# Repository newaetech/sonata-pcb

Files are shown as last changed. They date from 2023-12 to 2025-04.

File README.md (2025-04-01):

# Sonata PCB Sources for Development Board

Sonata is a system for evaluating the usage of [CHERIoT Ibex core](https://github.com/microsoft/cheriot-ibex) as a microcontroller for embedded, IoT and Operational Technology applications.
See the main [Sonata System](https://github.com/lowRISC/sonata-system) repository for more information.

This repository contains the source files for the PCB and related information about the development board.

Sonata is part of the [Sunburst Project](https://www.sunburst-project.org) funded by [UKRI](https://www.ukri.org/) / [DSbD](https://www.dsbd.tech/).

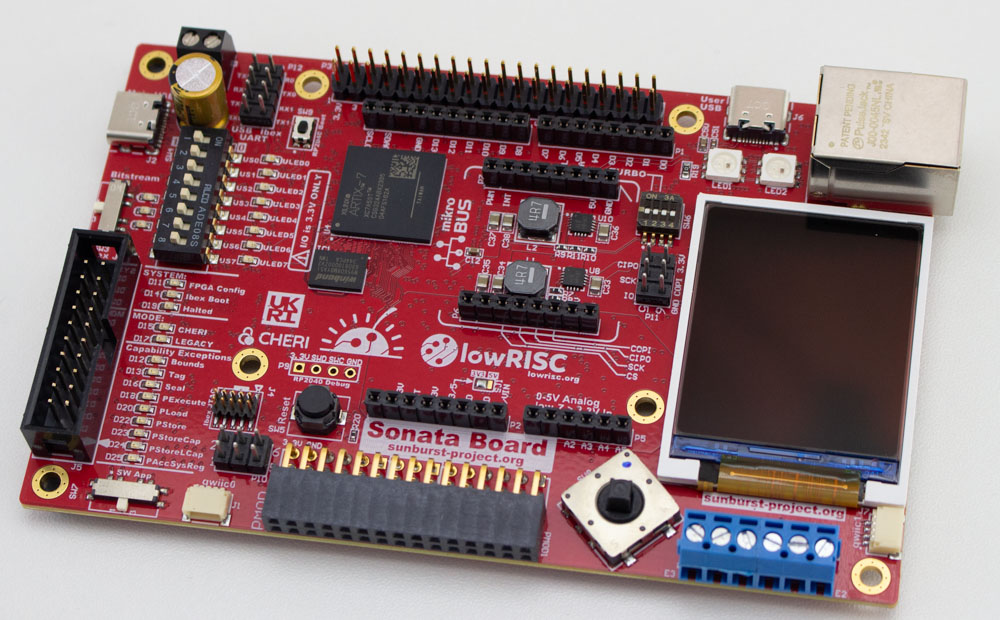
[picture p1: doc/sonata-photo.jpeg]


## Associated Repos for Testing

See the [https://github.com/newaetech/sonata-rp2040](https://github.com/newaetech/sonata-rp2040) repo for the RP2040 firmware.

See the [https://github.com/newaetech/sonata-fpga-test](https://github.com/newaetech/sonata-fpga-test) repo for the FPGA test bitstream project, which is used only for testing certain features, or can be used as the base for your own FPGA project. Most users should see the [Sonata System](https://github.com/lowRISC/sonata-system) repository instead to build the reference Sonata FPGA.

## License

Unless otherwise noted, everything in the repository is covered by the [Apache License](https://www.apache.org/licenses/LICENSE-2.0.html), Version 2.0. Where reference is made to the CC-SA license (particular for the PCB files), the license is the [Creative Commons Share Alike 4.0 License](https://creativecommons.org/licenses/by-sa/4.0/).

## PCB Status

### Sonata-One

Rev0.9 Gerbers are the production version. Prior gerbers are currently kept but will be removed (still available in the GIT history).

The original PCB was designed in Altium, and the design then ported to KiCAD. The production gerbers are generated from the Altium PCB.

### Sonata-XL (Sonata-A200)

A modified version of Sonata with a larger (Artix A200) FPGA is also available. This version was designed for various test environments.
It may be available in future versions.

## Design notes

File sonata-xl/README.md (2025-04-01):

# SonataXL

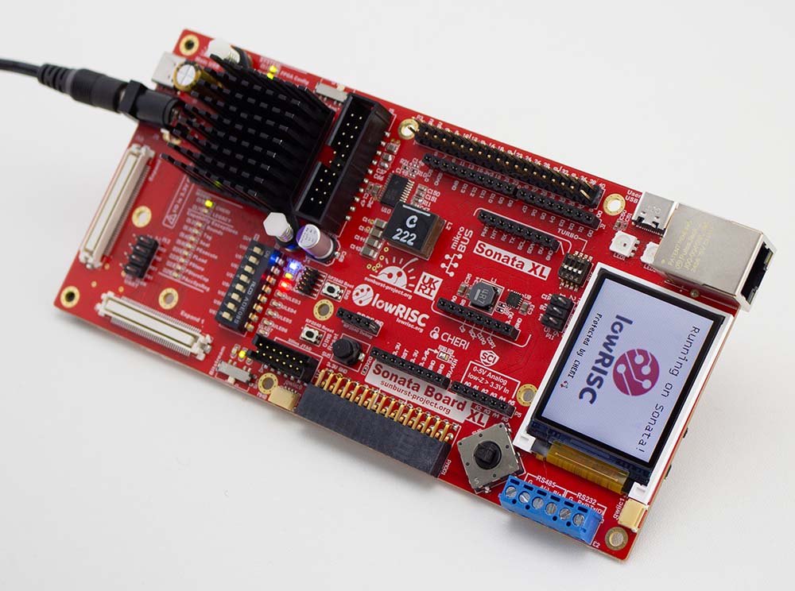
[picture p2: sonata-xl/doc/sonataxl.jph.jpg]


SonataXL has a larger A200 FPGA, as well as 2x high density pin headers for various expansion boards.

It uses the same drag & drop RP2040 firmware as the Sonata board. The only difference in peripherals is there
is no HyperRAM on this board.

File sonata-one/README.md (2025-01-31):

# Sonata-One PCB

This folder contains the Sonata-One PCB.

The original design was developed in Altium, which was then ported to KiCAD for better accessability.

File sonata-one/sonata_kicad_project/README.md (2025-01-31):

# SONATA-ONE-KICAD
 KiCAD Design files for Sonata PCB, part of the Sunburst Project
 
 Please sumit an issue if you discover problems with this repo. Design converted and refactored from the original altium files.

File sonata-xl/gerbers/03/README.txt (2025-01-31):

GENERAL
----------
Finish: ENIG
Soldermask: Red
Silkscreen: White
Board Thickness: 1.6mm

168 mm * 80 mm

Min drill = 0.2mm
Space/Trace = 5mil

PCB STACKUP:
--------------------------------
 .GTO Top Silkcreen
 .GTS Top Soldermask
 .GTL TOP COPPER       (LAYER 1)
 .G1  INNER 1          (LAYER 2)
 .G2  INNER 2          (LAYER 3)
 .G3  INNER 3          (LAYER 4)
 .G4  INNER 4          (LAYER 5)
 .G5  INNER 5          (LAYER 6)
 .G6  INNER 6          (LAYER 7)
 .GBL BOTTOM COPPER    (LAYER 8)
 .GTS Bottom Soldermask
 .GBO Bottom Silkscreen

ADDITIONAL FILES:
--------------------------------
 .NCDRILL - NC Drill
 .GTP Top Stencil
 .GBP Bottom Stencil
 .GM1 board routing/outline

BOARD CONSTRUCTION
--------------------------------
Standard board stackup spacing for 8-layer 0.062" PCB ok

E-TEST
------

PCBs must be 100% electrically tested. Can provide netlist in preferred format on request.

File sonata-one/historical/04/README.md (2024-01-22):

These gerbers had critical errors and have been removed to avoid accidents.

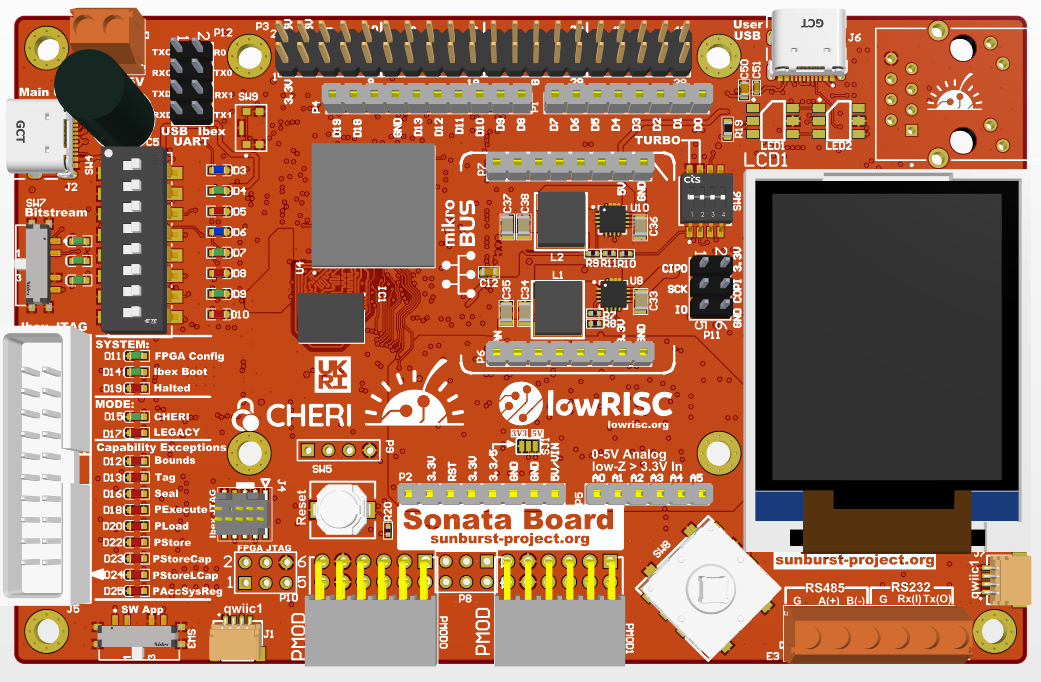
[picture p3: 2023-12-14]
doc/sonata-render.png

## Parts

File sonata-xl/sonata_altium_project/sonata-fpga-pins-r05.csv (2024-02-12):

# Altium Pin Report File
Pin Designator | Net Name | Display Name | IO Bank | IO Standard | Slew Rate | Drive Strength | IO Pin | Vref Pin | CLK Pin | Config Pin | Special Pin | Group | Differential Pair
A1 | HYPERRAM_DQ3 | IO_L9N_T1_DQS_AD7N_35
A2 | GND | GND
A3 | ANALOG5_N | IO_L8N_T1_AD14N_35
A4 | ANALOG5_P | IO_L8P_T1_AD14P_35
A5 | ANALOG2_N | IO_L3N_T0_DQS_AD5N_35
A6 | ANALOG2_P | IO_L3P_T0_DQS_AD5P_35
A7 | VCC1V8 | VCCO_35
A8 | APPSPI_CLK | IO_L12N_T1_MRCC_16
A9 | APPSPI_D3 | IO_L14N_T2_SRCC_16
A10 | APPSPI_D2 | IO_L14P_T2_SRCC_16
A11 | USRLED5 | IO_L4N_T0_15
A12 | GND | GND
A13 | USRSW6 | IO_L9P_T1_DQS_AD3P_15
A14 | USRSW7 | IO_L9N_T1_DQS_AD3N_15
A15 | USRSW4 | IO_L8P_T1_AD10P_15
A16 | USRSW5 | IO_L8N_T1_AD10N_15
A17 | VCCIO | VCCO_15
A18 | NetR172_3A | IO_L10N_T1_AD11N_15
B1 | HYPERRAM_DQ0 | IO_L9P_T1_DQS_AD7P_35
B2 | HYPERRAM_DQ5 | IO_L10N_T1_AD15N_35
B3 | MICROSD_DET | IO_L10P_T1_AD15P_35
B4 | ANALOG4_N | IO_L7N_T1_AD6N_35
B5 | GND | GND
B6 | ANALOG1_N | IO_L2N_T0_AD12N_35
B7 | ANALOG1_P | IO_L2P_T0_AD12P_35
B8 | ANALOG5_DIGITAL | IO_L12P_T1_MRCC_16
B9 | ANALOG4_DIGITAL | IO_L11N_T1_SRCC_16
B10 | VCCIO | VCCO_16
B11 | USRLED4 | IO_L4P_T0_15
B12 | USRLED3 | IO_L3N_T0_DQS_AD1N_15
B13 | USRLED0 | IO_L2P_T0_AD8P_15
B14 | USRLED1 | IO_L2N_T0_AD8N_15
B15 | GND | GND
B16 | USRSW2 | IO_L7P_T1_AD2P_15
B17 | USRSW3 | IO_L7N_T1_AD2N_15
B18 | NetR172_1A | IO_L10P_T1_AD11P_15
C1 | HYPERRAM_DQ6 | IO_L16N_T2_35
C2 | HYPERRAM_nRST | IO_L16P_T2_35
C3 | VCC1V8 | VCCO_35
C4 | ANALOG4_P | IO_L7P_T1_AD6P_35
C5 | ANALOG0_N | IO_L1N_T0_AD4N_35
C6 | ANALOG0_P | IO_L1P_T0_AD4P_35
C7 | NAVSW_2 | IO_L4N_T0_35
C8 | GND | GND
C9 | ANALOG3_DIGITAL | IO_L11P_T1_SRCC_16
C10 | APPSPI_D1 | IO_L13N_T2_MRCC_16
C11 | APPSPI_D0 | IO_L13P_T2_MRCC_16
C12 | USRLED2 | IO_L3P_T0_DQS_AD1P_15
C13 | VCCIO | VCCO_15
C14 | ANALOG2_DIGITAL | IO_L1N_T0_AD0N_15
C15 | NetR173_2A | IO_L12N_T1_MRCC_15
C16 | USR_JTAG_TRST | IO_L20P_T3_A20_15
C17 | SER0_TX | IO_L20N_T3_A19_15
C18 | GND | GND
D1 | GND | GND
D2 | HYPERRAM_DQ7 | IO_L14N_T2_SRCC_35
D3 | SELSW0 | IO_L12N_T1_MRCC_35
D4 | ETHMAC_CIPO | IO_L11N_T1_SRCC_35
D5 | ETHMAC_COPI | IO_L11P_T1_SRCC_35
D6 | VCC1V8 | VCCO_35
D7 | NAVSW_4 | IO_L6N_T0_VREF_35
D8 | NAVSW_1 | IO_L4P_T0_35
D9 | RGBLED0 | IO_L6N_T0_VREF_16
D10 | APPSPI_CS | IO_L19N_T3_VREF_16
D11 | GND | GND
D12 | USRSW0 | IO_L6P_T0_15
D13 | USRSW1 | IO_L6N_T0_VREF_15
D14 | ANALOG1_DIGITAL | IO_L1P_T0_AD0P_15
D15 | NetR173_1A | IO_L12P_T1_MRCC_15
D16 | VCCIO | VCCO_15
D17 | NetR176_3A | IO_L16N_T2_A27_15
D18 | SER0_RX | IO_L21N_T3_DQS_A18_15
E1 | HYPERRAM_DQ4 | IO_L18N_T2_35
E2 | HYPERRAM_DQ1 | IO_L14P_T2_SRCC_35
E3 | ETHMAC_SCLK | IO_L12P_T1_MRCC_35
E4 | GND | GND
E5 | ANALOG3_N | IO_L5N_T0_AD13N_35
E6 | ANALOG3_P | IO_L5P_T0_AD13P_35
E7 | NAVSW_3 | IO_L6P_T0_35
E8 | VCC1V8 | VCCBATT_0
E9 | FPGA_CCLK | CCLK_0
E10 | FPGA_TCK | TCK_0
E11 | FPGA_TDI | TDI_0
E12 | FPGA_TMS | TMS_0
E13 | FPGA_TDO | TDO_0
E14 | GND | GND
E15 | USR_JTAG_TCK | IO_L11P_T1_SRCC_15
E16 | NetR172_2A | IO_L11N_T1_SRCC_15
E17 | NetR176_2A | IO_L16P_T2_A28_15
E18 | SER1_TX | IO_L21P_T3_DQS_15
F1 | HYPERRAM_RWDS | IO_L18P_T2_35
F2 | VCC1V8 | VCCO_35
F3 | SELSW2 | IO_L13N_T2_MRCC_35
F4 | SELSW1 | IO_L13P_T2_MRCC_35
F5 | NAVSW_0 | IO_0_35
F6 | USRUSB_V_N | IO_L19N_T3_VREF_35
F7 | GND | GND
F8 | VCCINT | VCCINT
F9 | GND | GND
F10 | VCCINT | VCCBRAM
F11 | GND | GND
F12 | VCC1V8 | VCCAUX
F13 | USRLED6 | IO_L5P_T0_AD9P_15
F14 | USRLED7 | IO_L5N_T0_AD9N_15
F15 | NetR174_3A | IO_L14P_T2_SRCC_15
F16 | NetR174_2A | IO_L14N_T2_SRCC_15
F17 | GND | GND
F18 | NetR194_2A | IO_L22N_T3_A16_15
G1 | USRUSB_SPD | IO_L17N_T2_35
G2 | HYPERRAM_CK_N | IO_L15N_T2_DQS_35
G3 | USRUSB_VMO | IO_L20N_T3_35
G4 | USRUSB_VPO | IO_L20P_T3_35
G5 | VCC1V8 | VCCO_35
G6 | USRUSB_V_P | IO_L19P_T3_35
G7 | VCCINT | VCCINT
G8 | GND | GND
G9 | VCCINT | VCCINT
G10 | GND | GND
G11 | VCCINT | VCCBRAM
G12 | GND | GND
G13 | ANALOG0_DIGITAL | IO_0_15
G14 | NetR174_4A | IO_L15N_T2_DQS_ADV_B_15
G15 | VCCIO | VCCO_15
G16 | NetR173_4A | IO_L13N_T2_MRCC_15
G17 | USR_JTAG_TDI | IO_L18N_T2_A23_15
G18 | SER1_RX | IO_L22P_T3_A17_15
H1 | HYPERRAM_DQ2 | IO_L17P_T2_35
H2 | HYPERRAM_CK_P | IO_L15P_T2_DQS_35
H3 | GND | GND
H4 | USRUSB_SOFTCN | IO_L21N_T3_DQS_35
H5 | ETHMAC_CS | IO_L24N_T3_35
H6 | ETHMAC_INTR | IO_L24P_T3_35
H7 | GND | GND
H8 | VCCINT | VCCINT
H9 | XADC_AGND | GNDADC_0
H10 | +1V85_XADC_VCC | VCCADC_0
H11 | GND | GND
H12 | VCC1V8 | VCCAUX
H13 | GND | GND
H14 | NetR174_1A | IO_L15P_T2_DQS_15
H15 | USR_JTAG_TMS | IO_L19N_T3_A21_VREF_15
H16 | NetR173_3A | IO_L13P_T2_MRCC_15
H17 | NetR172_4A | IO_L18P_T2_A24_15
H18 | VCCIO | VCCO_15
J1 | VCC1V8 | VCCO_35
J2 | HYPERRAM_CS | IO_L22N_T3_35
J3 | USRUSB_OE | IO_L22P_T3_35
J4 | USRUSB_RCV | IO_L21P_T3_DQS_35
J5 | ETHMAC_RST | IO_25_35
J6 | GND | GND
J7 | VCCINT | VCCINT
J8 | GND | GND
J9 | XADC_VREF_N | VREFN_0
J10 |  | VP_0
J11 | VCCINT | VCCINT
J12 | GND | GND
J13 | NetR176_1A | IO_L17N_T2_A25_15
J14 | USR_JTAG_TDO | IO_L19P_T3_A22_15
J15 | NetR186_1 | IO_L24N_T3_RS0_15
J16 | GND | GND
J17 | NetR194_3A | IO_L23P_T3_FOE_B_15
J18 | NetR194_1A | IO_L23N_T3_FWE_B_15
K1 | USRUSB_VBUSDETECT | IO_L23N_T3_35
K2 | USRUSB_SUS | IO_L23P_T3_35
K3 | CHERIERR3 | IO_L2P_T0_34
K4 | VCCIO | VCCO_34
K5 | LED_LEGACY | IO_L5P_T0_34
K6 | CHERIERR0 | IO_0_34
K7 | GND | GND
K8 | VCCINT | VCCINT
K9 |  | VN_0
K10 | XADC_VREF_P | VREFP_0
K11 | GND | GND
K12 | VCC1V8 | VCCAUX
K13 | NetR176_4A | IO_L17P_T2_A26_15
K14 | VCCIO | VCCO_15
K15 | NetR194_4A | IO_L24P_T3_RS1_15
K16 | NetR187_1 | IO_25_15
K17 | NetR175_2A | IO_L1P_T0_D00_MOSI_14
K18 | RP2040_TX | IO_L1N_T0_D01_DIN_14
L1 | CHERIERR1 | IO_L1P_T0_34
L2 | GND | GND
L3 | CHERIERR4 | IO_L2N_T0_34
L4 | LED_CHERI | IO_L5N_T0_34
L5 | LED_BOOTOK | IO_L6N_T0_VREF_34
L6 | LED_HALTED | IO_L6P_T0_34
L7 | VCCINT | VCCINT
L8 | GND | GND
L9 |  | DXN_0
L10 |  | DXP_0
L11 | VCCINT | VCCINT
L12 | GND | GND
L13 | NetR175_3A | IO_L6P_T0_FCS_B_14
L14 | NetR177_3A | IO_L2P_T0_D02_14
L15 | NetR183_1A | IO_L3P_T0_DQS_PUDC_B_14
L16 | NetR177_4A | IO_L3N_T0_DQS_EMCCLK_14
L17 | VCCIO | VCCO_14
L18 | NetR175_1A | IO_L4P_T0_D04_14
M1 | CHERIERR2 | IO_L1N_T0_34
M2 | CHERIERR8 | IO_L4N_T0_34
M3 | CHERIERR7 | IO_L4P_T0_34
M4 | 485_DE | IO_L16P_T2_34
M5 | GND | GND
M6 | 485_DI | IO_L18P_T2_34
M7 | GND | GND
M8 | VCCINT | VCCINT
M9 | GND | GND
M10 | VCCINT | VCCINT
M11 | GND | GND
M12 | VCC1V8 | VCCAUX
M13 | NetR169_1 | IO_L6N_T0_D08_VREF_14
M14 | NetR177_2A | IO_L2N_T0_D03_14
M15 | GND | GND
M16 | NetR175_4A | IO_L10P_T1_D14_14
M17 | RP2040_RX | IO_L10N_T1_D15_14
M18 | NetR189_4A | IO_L4N_T0_D05_14
N1 | CHERIERR6 | IO_L3N_T0_DQS_34
N2 | CHERIERR5 | IO_L3P_T0_DQS_34
N3 | VCCIO | VCCO_34
N4 | 485_REn | IO_L16N_T2_34
N5 | LCD_BACKLIGHT | IO_L13P_T2_MRCC_34
N6 | 232_RX | IO_L18N_T2_34
N7 | VCCINT | VCCINT
N8 | GND | GND
N9 | VCCINT | VCCINT
N10 | GND | GND
N11 | VCCINT | VCCINT
N12 | GND | GND
N13 | VCCIO | VCCO_14
N14 | NetR182_3A | IO_L8P_T1_D11_14
N15 | NetR177_1A | IO_L11P_T1_SRCC_14
N16 | NetR182_4A | IO_L11N_T1_SRCC_14
N17 | NetR168_1 | IO_L9P_T1_DQS_14
N18 | GND | GND
P1 | GND | GND
P2 | NetR178_1A | IO_L15P_T2_DQS_34
P3 | 232_TX | IO_L14N_T2_SRCC_34
P4 | RP2040_SPARE | IO_L14P_T2_SRCC_34
P5 | LCD_CS | IO_L13N_T2_MRCC_34
P6 | VCCIO | VCCO_34
P7 | FPGA_INITB | INIT_B_0
P8 | VCCIO | CFGBVS_0
P9 | FPGA_PGMB | PROGRAM_B_0
P10 | FPGA_DONE | DONE_0
P11 | VCCIO | M2_0
P12 | VCCIO | M0_0
P13 | VCCIO | M1_0
P14 | NetR191_4A | IO_L8N_T1_D12_14
P15 | MAINCLK | IO_L13P_T2_MRCC_14
P16 | VCCIO | VCCO_14
P17 | NetR179_3A | IO_L12P_T1_MRCC_14
P18 | NetR182_2A | IO_L9N_T1_DQS_D13_14
R1 | NetR178_2A | IO_L17P_T2_34
R2 | 485_RO | IO_L15N_T2_DQS_34
R3 | LCD_COPI | IO_L11P_T1_SRCC_34
R4 | GND | GND
R5 | LCD_CLK | IO_L19N_T3_VREF_34
R6 | LCD_RST | IO_L19P_T3_34
R7 | MICROSD_DAT1 | IO_L23P_T3_34
R8 | MICROSD_CMD | IO_L24P_T3_34
R9 | VCCIO | VCCO_0
R10 | NetR189_1A | IO_25_14
R11 | NetR183_3A | IO_0_14
R12 | NetR188_3A | IO_L5P_T0_D06_14
R13 | NetR181_3A | IO_L5N_T0_D07_14
R14 | GND | GND
R15 | NetR182_1A | IO_L13N_T2_MRCC_14
R16 | NetR191_1A | IO_L15P_T2_DQS_RDWR_B_14
R17 | NetR191_2A | IO_L12N_T1_MRCC_14
R18 | NetR191_3A | IO_L7P_T1_D09_14
T1 | NetR178_3A | IO_L17N_T2_34
T2 | VCCIO | VCCO_34
T3 | NetR180_1A | IO_L11N_T1_SRCC_34
T4 | FPGAIO_TURBO | IO_L12N_T1_MRCC_34
T5 | NRST | IO_L12P_T1_MRCC_34
T6 | NetR184_2A | IO_L23N_T3_34
T7 | GND | GND
T8 | MICROSD_DAT3 | IO_L24N_T3_34
T9 | NetR185_2A | IO_L24P_T3_A01_D17_14
T10 | NetR185_3A | IO_L24N_T3_A00_D16_14
T11 | NetR188_1A | IO_L19P_T3_A10_D26_14
T12 | VCCIO | VCCO_14
T13 | NetR181_1A | IO_L23P_T3_A03_D19_14
T14 | RP2040_CLK | IO_L14P_T2_SRCC_14
T15 | NetR183_4A | IO_L14N_T2_SRCC_14
T16 | NetR190_2A | IO_L15N_T2_DQS_DOUT_CSO_B_14
T17 | GND | GND
T18 | NetR190_4A | IO_L7N_T1_D10_14
U1 | NetR178_4A | IO_L7P_T1_34
U2 | NetR180_3A | IO_L9P_T1_DQS_34
U3 | NetR171_1 | IO_L8N_T1_34
U4 | LCD_DC | IO_L8P_T1_34
U5 | VCCIO | VCCO_34
U6 | MICROSD_CLK | IO_L22N_T3_34
U7 | NetR170_1A | IO_L22P_T3_34
U8 | NetR184_1A | IO_25_34
U9 | NetR170_4A | IO_L21P_T3_DQS_34
U10 | GND | GND
U11 | NetR189_3A | IO_L19N_T3_A09_D25_VREF_14
U12 | NetR188_2A | IO_L20P_T3_A08_D24_14
U13 | NetR188_4A | IO_L23N_T3_A02_D18_14
U14 | NetR181_2A | IO_L22P_T3_A05_D21_14
U15 | VCCIO | VCCO_14
U16 | NetR190_3A | IO_L18P_T2_A12_D28_14
U17 | NetR179_4A | IO_L17P_T2_A14_D30_14
U18 | NetR190_1A | IO_L17N_T2_A13_D29_14
V1 | NetR180_2A | IO_L7N_T1_34
V2 | NetR180_4A | IO_L9N_T1_DQS_34
V3 | GND | GND
V4 | MICROSD_DAT0 | IO_L10N_T1_34
V5 | MICROSD_DAT2 | IO_L10P_T1_34
V6 | NetR184_3A | IO_L20N_T3_34
V7 | NetR170_3A | IO_L20P_T3_34
V8 | VCCIO | VCCO_34
V9 | NetR170_2A | IO_L21N_T3_DQS_34
V10 | NetR185_1A | IO_L21P_T3_DQS_14
V11 | NetR185_4A | IO_L21N_T3_DQS_A06_D22_14
V12 | NetR189_2A | IO_L20N_T3_A07_D23_14
V13 | GND | GND
V14 | NetR181_4A | IO_L22N_T3_A04_D20_14
V15 | NetR183_2A | IO_L16P_T2_CSI_B_14
V16 | NetR179_1A | IO_L16N_T2_A15_D31_14
V17 | NetR179_2A | IO_L18N_T2_A11_D27_14
V18 | VCCIO | VCCO_14

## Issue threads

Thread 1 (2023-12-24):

0.2 pcb - FTDI chip has shorted EEPROM pins

colinoflynn, 2023-12-24:
At some point between initial design & PCB layout the FTDI EEPROM got dragged and Altium decided we should short those pins together. This wasn't caught & requires a PCB mod to fix. Otherwise the FTDI chip won't come online.

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

colinoflynn, 2024-01-12:
Issue is fixed on 0.3 PCB (now on order) & will be tested once board is built. Issue will be closed once fix is confirmed.

Closed 2024-02-25.

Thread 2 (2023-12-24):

0.2 pcb - activeBOM PN issue with AVCC regulator

colinoflynn, 2023-12-24:
P/N for AVCC regulator was wrong on initial DK order, need to check if that was an issue with ActiveBom & the manufacture solution. P/N in the schematic sheet is correct.

Closed 2024-02-25.

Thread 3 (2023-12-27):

0.2 pcb - LCD connector is mirrored

colinoflynn, 2023-12-27:
LCD connector is mirrored & requires flywires to mount LCD:

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

colinoflynn, 2024-01-12:
Issue is fixed on 0.3 PCB (now on order) & will be tested once board is built. Issue will be closed once fix is confirmed.

Closed 2024-02-25.

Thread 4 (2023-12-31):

0.2 pcb - DIN not routed to RP2040

colinoflynn, 2023-12-31:
Do to a pin swap marathon where the DIN wasn't locked, it no longer routes to the RP2040. This means the FPGA configuration won't work from the RP2040 without a flywire on the PCB. This should run from one side of R66 to the RPH_G3_SCL pin (which is on the R-Pi header).

colinoflynn, 2024-01-03:
Updated routing moves SCK/DIN/DOUT to one bank, moves a few misc signals ot other bank. Keeps all the RPH on one bank for future speed reasons.

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

colinoflynn, 2024-01-12:
Issue is fixed on 0.3 PCB (now on order) & will be tested once board is built. Issue will be closed once fix is confirmed.

Closed 2024-02-25.

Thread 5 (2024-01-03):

0.2 pcb - User JTAG TCK not routed to clock capable pin

GregAC, 2024-01-03:
The USR_JTAG_TCK net is routed to pin H17 which is not a clock capable pin. Our JTAG TAP implementation uses TCK as a clock (i.e. in a `alway_ff @(posedge tck)` block). As TCK doesn't need to be fast and has little logic connected to it this may not be a problem (we could always refactor the TAP so it doesn't use TCK directly as a clock as well) however it would be preferable for it to be routed to a clock capable pin if possible.

GregAC, 2024-01-03:
@colinoflynn please note

colinoflynn, 2024-01-03:
Oops! Might be another pin-swap problem, will re-route it to a clock pin if reasonable. For now I'd just delegate it to a warning, with the small(ish) logic I probably wouldn't worry about that. I'll get @jpcrypt's input as well once he's available.

GregAC, 2024-01-03:
I've got JTAG over FTDI working so I can load and debug programs on the Ibex demo system with a 10 MHz JTAG clock (or at least that's what OpenOCD claims...)

So a fix for this is in the nice to have bucket but certainly not essential. Could be it's not always reliable at 10 MHz, could try to do some stress testing to determine this. We can always lower the speed if needed.

colinoflynn, 2024-01-03:
Pinswap:
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

colinoflynn, 2024-01-03:
Now routed to a SRCC pin (assume SRCC is fine & not MRCC)

colinoflynn, 2024-01-12:
Issue is on 0.3 PCB (now on order) & will be tested once board is built. Issue will be closed once fix is confirmed.

Closed 2024-02-25.

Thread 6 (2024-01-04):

0.2 pcb - SW7/SW3 are swapped

colinoflynn, 2024-01-04:
It seems SW7 (which should go to RP2040) & SW3 (which should go to FPGA) are swapped.

colinoflynn, 2024-01-12:
Issue is on 0.3 PCB (now on order) & will be tested once board is built. Issue will be closed once fix is confirmed.

Closed 2024-02-25.

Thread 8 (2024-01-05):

0.2 pcb - RS485 silkscreen error

colinoflynn, 2024-01-05:
A is negative, B is positive.

colinoflynn, 2024-01-05:
Also changed the net naming on 485 nets to fix a combination of errors & unclear net names:

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

Closed 2024-02-25.

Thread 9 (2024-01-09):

0.2 pcb - LCD_BACKLIGHT pin doesn't go anywhere

colinoflynn, 2024-01-09:
As reported by @GregAC - LCD_BACKLIGHT isn't routed to the FPGA (but does have a single resistor on it so didn't get an ERC when checking).

Easiest is just for the LCD on, by shorting between these pins:
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

The relevant schematic section:
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

You can also run a bodge wire from the side of R133 that connects to the Q2 gate to an FPGA pin. But in practice the LCD shouldn't need backlight dimming, so just turning it ON is fine.

GregAC, 2024-01-09:
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

I just used a big blog of solder to bridge the connections, looks to be working well

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

colinoflynn, 2024-01-12:
Issue is fixed on 0.3 PCB (now on order) & will be tested once board is built. Issue will be closed once fix is confirmed.

Closed 2024-02-25.

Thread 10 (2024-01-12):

0.2 pcb - Level shifter transistor for neopixel is too slow (Q3)

GregAC, 2024-01-12:
I was having issues getting the RGB LEDs to work so took a look with a logic analyser and found a huge delay (~400ns) between the falling edge of the `rgbled0` net and the corresponding rising edge (inverted logic due to shifter) at the DIN pin of the first RGB LED. There was also a smaller delay between the rising edge of  `rgbled0` and the falling edge of the DIN pin.

The timing here is down to the chosen transistor, described in the schematic as a 'DMN3200U' datasheet is here: https://www.diodes.com/assets/Datasheets/ds31188.pdf

The sum of turn on delay and rise time is ~80ns and the sum of turn off delay and rise time is ~570ns. The ws2813b protocol needs timing accurate to ~100ns so this transistor is too slow.

As it happens you can get them to work by taking the delays into account in the hardware generating the signal but the timing of the resulting signal at the DIN is out of spec even if it does manage to still work. Plus given there will be variation across transistors and variation across how out of spec you could go for each ws2813b you may need to 'calibrate' each board separately to get things to work.

A faster transistor would be far better. I happened to have some BSS138 (https://www.diodes.com/assets/Datasheets/BSS138.pdf) on hand so I switched Q3 for one of those and that seems to work fine.

Here's some logic analyzer traces demonstrating the problem

The first shows behaviour with the original transistor, Channel 7 is the FPGA output mirrored to a header pin (and inverted so it matches what should appear on DIN on the RGB LED), Channel 6 is DIN on the first RGB LED. As you can see there is a long time between Channel 7 going high (meaning the `rgbled0` net falls and Channel 6 rising). Channel 6 barely hits the top of its voltage range before dipping again for the next edge.

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

After the transistor swap it looks like this:

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

Far better rise and fall times.

I did also measure at the actual gate of Q3 (fiddlier as I have to hold the probe in place can't clip it) and that was showing the gate was rapidly charging/discharging so it was definitely the transistor switch time itself at issue, not the time taken to drive the gate high/low.

@alees24 @hcallahan-lowrisc please note

marnovandermaas, 2024-01-12:
Great find Greg!

colinoflynn, 2024-01-12:
Issue is on 0.3 PCB (now on order) & will be tested once board is built. Issue will be closed once fix is confirmed.

Closed 2024-02-25.

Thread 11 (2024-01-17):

0.2pcb/0.3pcb - ethernet jack is missing connections

colinoflynn, 2024-01-17:
Ethernet jack is missing:

* Center Tap (CT's) should go to AVCC.
* Termination resistors on RX & TX pair.

Here is the dev board reference:
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

Here is Sonata:
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

The quick fix is this sort of hackery, where the resistors are 50 ohm, and capacitor is 100nF. The capacitor may not be required, in which case you could use just a 100 ohm across the transformer:

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

Note the ethernet has other issues on the build - may need to remove the crystal (TBD)

colinoflynn, 2024-01-17:
Here is a photo of one bodge version:

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

colinoflynn, 2024-01-18:
This is fixed on the 0.4 PCB.

Closed 2024-02-25.

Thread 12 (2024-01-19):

0.2pcb/0.3pcb/0.4pcb - RGB leds might come up with random color

colinoflynn, 2024-01-19:
Not repeatable, but some LEDs seem to come up with random color (seen on 1/6 boards so far). Hypothetically related to data line getting pulled down on start-up, and may also have some toggling due to the power supply sequencing.

May try to change the MOSFET gate to have a pull-down instead of a pull-up, which will result in the data line being held high.

I've also seen some reports of people having issues with the WS2813B leds & them being sensitive to solder temp:

* https://www.eevblog.com/forum/projects/am-i-just-unlucky-or-worldsemi-ws2813-leds-are-crappy/
* https://www.makerfabs.cc/article/why-ws2812-sk6812-failures-after-smt-soldering.html

Hard to troubleshoot with small batch size. Will make the pull-down option on next rev or will test with a simple PCB mod:

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

alees24, 2024-01-23:
A couple of other points: Although LEDs have on a couple of occasions been observed to illuminate spontaneously without having previously been programmed with valid data, the normal failure mode is that the 5V rail has not fully discharged and the RGBLEDs have internally retained their most recently-programmed state. It is to this colour, rather than a random colour, that they commonly return when normal power is restored.
This is suspected of happening on all boards, having been repeatedly demonstrated on the two that we have in the lowRISC office, but it is not normally observed on other boards because they have not recently been programmed with colour information.

colinoflynn, 2024-02-02:
There may be two separate issues here, but not sure if worth making two issues:

1. The random colour power-on which is observed so far only on one PCB.
2. The memory effect - this is due to the 5V rail going down slower than the 3.3V rail. Also I'd put into this item the problem of the FPGA being reset/reprogrammed, and no longer using the RGB led.

Possible solution to 2 is to use the RP2040 to drive a power-off sequence to the LED when the RP2040 detects the 'done' pin indicating the device isn't programmed (either on power-on, OR if the device is reprogrammed from any interface). This would avoid needing a separate power enable for the RGBLED, which will require shuffling a FPGA pin.

I've tested the "fix" I pushed (pull-down) and it doesn't fix the reset/memory issue. TBD if it fixes the random colour issue, as that needs to be tested on the board that exhibits it.

alees24, 2024-02-07:
With the pull down mod (but, just to confirm, still the slow MOSFET) the original 'problem board' seems to have lost its ability to retain and reinstate colours beyond about 3 seconds. Disrupting the power for up to about 3 seconds still exhibits the memory effect, although looking at the signals using the analog inputs of the logic analyzer, there is now no glitching of the DIN/BIN line to the RGBLEDs and it rises along with the 5V rail, tracking it exactly through the 1k pull up, with no lag.

These devices interpret the DIN/BIN being low for >= 280us as the 'reset' signal and set the LEDs to the programmed value. In normal use the delay between programming and signaling a reset seems not to matter, and note that it's not the rising edge of the DIN/BIN that triggers the change, but still being low after ~280us. Holding it low when idle, and then issuing the programming sequence _just once_ in response the 'nav' button being pressed, I am able to set the LEDs to the colour of my choosing using the DIP switches.

It is true that DIN/BIN takes > 280us to reach the 2.7V 'Vin high' threshold at power on, but that's because it's taking that long for the 5V rail to rise from a quiescent level of ca. 630mv to 2.7V, and although I guess there's a chance that a shorter rise time would sidestep the memory effect, it seems unlikely that it can be eliminated completely without explicit programming of the LEDs on power up.

No more information at this stage on the 'unprompted, random and not remembered illumination' It hasn't been seen again post-mod, but it was a very infrequent occurrence anyway.

alees24, 2024-02-08:
@colinoflynn I wonder whether the memory effect could be sidestepped by experimentally removing C5 which would both cause the 5V rail to drop faster, and produce a sharper rise when powered is connected. A smaller capacitor may eliminate the memory effect?

Whilst the LEDs are illuminated, if the FPGA is reprogrammed with a design that doesn't drive the LEDs, they will of course remain on indefinitely. The user is surely less likely to remove the power for just a couple of seconds, so if this issue requires further discussion/attention, we should perhaps focus on the the FPGA reprogramming case rather than the memory effect.

It's not really on a par with accepting that memory contents must be put into a known, defined state at power up/reset, since there is a clear user-visible effect, but personally I'm happy for us to leave this to 'Sonata 2' as and when that happens, and just record it as a quirk/erratum of this board.

colinoflynn, 2024-02-08:
Ok, good news on random light I think then right? I'll probably leave major fixes to a possible later rev, although with this first batch we'll have a better sample size to actually see if we get random power-on "normally" either (e.g., maybe your board had other soldering issues beyond those we know about).

I wouldn't want to mess with C5 as that could impact the stability of the (more important) regulators.

On the next rev (e.g., for production) I'll see if I can at least throw a connection to the RP2040, which we could use to clear it if we're really bothered by it later. But I think for now it sounds like we've reached a good enough state to continue with production...

colinoflynn, 2024-02-09:
There is now a 07 rev which allows the RP2040 (via a 1K resistor) to drive the RGBLED. If needed we can have the RP2040 drive this potentially.

colinoflynn, 2024-02-25:
Leaving open until confirmed RP2040 "fix" works fully.

colinoflynn, 2024-03-12:
The RP2040 can turn these off OK. Quick code to do so for ref:

```
import machine
import neopixel

class NeoPixelInverted(neopixel.NeoPixel):
  def __init__(self, pin, n, bpp=3, timing=1):
    super().__init__(pin, n, bpp, (850, 400, 450, 800))

  def write(self):
    self.pin.value(1)
    super().write()
    self.pin.value(1)

np = NeoPixelInverted(machine.Pin(15), 2)

np[0] = (0, 0, 0) # off
np[1] = (0, 0, 0) # off

np.write()

#Back to floating so FPGA can take control again
p15 = machine.Pin(15, machine.Pin.IN)
```

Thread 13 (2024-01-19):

0.4pcb - untented vias

colinoflynn, 2024-01-19:
A couple vias on the 0.4pcb rev are untented in repo files. This was fixed by fab, but keeping this issue until fixed files are pushed (will be a 0.4A rev, won't make a new release just for that).

Won't actually impact anything, just looks odd having a couple untented vias.

Closed 2024-01-22.

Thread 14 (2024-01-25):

0.2pcb/0.3pcb/0.4pcb/0.5pcb RPI Header may require on-board pull-up resistors

alees24, 2024-01-25:
The I2C bus to pins 3 (RPH_G2_SDA) and 5 (RPH_G3_SCL) does not have on-board pull-up resistors but with Raspberry Pi HATs it is the responsibility of the controller SoC (Sonata FPGA) to provide bus termination when these pins are used as I2C rather than GPIO. Probing the Raspberry Pi 4 when driving the Sense HAT indicates the presence of pull ups, whilst no such resistors are present on the HATs themselves.

I2C pull-up resistors are typically 1.8k to 3.3k, and whilst the weak internal pull-ups of the FPGA pins may be enabled, these offer a resistance of between 10k and 37k (calculated from the Xilinx Artix-7 datasheet).

Experimentally, _on one particular board_ enabling the internal pull-ups is sufficient to operate in Standard-mode (100kbit/s), but the SI starts to fall apart below Fast-mode (400kbit/s). (Aside: It does function with current I2C test software, but this may be only because the bit rate is actually around 290kbit/s with the current settings calculated by the software.)

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

With external pull-up resistors present (3.3k and 5.1k because they were to hand), operation up to Fast-mode Plus is possible (though, again this is a claimed 1Mbit/s, but actual measurements presently indicate 590kbit/s)

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

The two images above show Standard-mode operation (100kbit/s) and the longer rise time - although not especially marked - can be seen.

colinoflynn, 2024-01-26:
Resistors are now on the 0.6 PCB, 1.8K pull-ups. They are mounted somewhat "out of the way" to make it a little easier for someone to modify them:

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

Closed 2024-02-25.

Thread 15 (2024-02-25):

0.8pcb - PUDC floating

colinoflynn, 2024-02-25:
Presumably at some point PUDC got pin-swapped and no longer has it's pull resistor. Either way production mod can easily make this a pull-down, which should mean weak pull-ups on all FPGA pins.

colinoflynn, 2024-02-25:
Marking fixedinrepo as mod documented on schematic, haven't updated PCB yet until we get a proper 0.9

colinoflynn, 2024-02-28:
The fix is soldering a resistor between pin 22 of the R-Pi header & the GND pin next to it:
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

colinoflynn, 2024-05-23:
This is now fixed in latest rev (0.9), default is now a pull-up on PUDC which disables pull-ups on I/O pins. But both are available so we can change the default back to this behavior.

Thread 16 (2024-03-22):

Permit store local capability exception

marnovandermaas, 2024-03-22:
In the latest CHERIoT ISA, the store local capability exception is removed. In future revisions of our board, it would be good to remove this LED:
https://github.com/microsoft/cheriot-sail/commit/3d13d24ff974c48897eaf79ac115ac8bbefbc536

colinoflynn, 2024-03-22:
Talk about convenient... that pin can be used to turn off the RGBLED power supply in the next revision then!

marnovandermaas, 2024-05-21:
Actually, this is still a debug feature in CHERIoT Ibex, which can be turned on using a CSR write: https://github.com/lowRISC/sonata-system/blob/6b4fafa9deb16518d98d2627d5e6a3b39cf70103/sw/cheri/error_leds/error.S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
Let's leave this in until that is removed.

Closed 2024-05-21.

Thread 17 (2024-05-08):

KSZ8851SNL missing pull-up resistor for INTRN pin

nbdd0121, 2024-05-08:
The INTRN pin of KSZ8851SNL requires an external 4.7kΩ pull-up resistor which is currently missing.

colinoflynn, 2024-05-08:
Is turning on the FPGA pull-up sufficient for now? We may be able to fit one as a mod on the PCBs that haven't been sent, but it would better if there was a soft solution for now.

nbdd0121, 2024-05-08:
Yes FPGA pull-up seems to be working:

https://github.com/lowRISC/sonata-system/blob/990e491575faec4d297f848c5895e2d54fc07695/data/pins_sonata.xdc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

Although I am not sure if this matches the 4.7kΩ requirement.

colinoflynn, 2024-05-08:
Ok phew! The 4.7kOhm should just affect signal speed I'm guessing (e.g., interrupt may be slower on rising edge). We can add the pads at least I think for next PCB spin, but won't do it as a production mod.

colinoflynn, 2024-05-23:
This is now fixed on latest rev (0.9).

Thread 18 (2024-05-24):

`RPH_G7_CE1` misnamed

marnovandermaas, 2024-05-24:
In the schematic `RPH_G7_CE1` is erroneously labelled as GPIO 8: `RPH_G8_CE1`.

colinoflynn, 2024-06-05:
Fixed! Thanks for catching that.

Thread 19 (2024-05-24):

Clarifying RPI Hat SPI pin names

marnovandermaas, 2024-05-24:
I suggest we label GPIO 7-11 with SPI0, for example: `rph_g11_spi0_sclk`.

Then label GPIO 16-21 with SPI1.

I also suggest labelling the chip selects for SPI1 which are currently:
- `rph_g17` for chip select 1.
- `rph_g18` for chip select 0.

colinoflynn, 2024-06-05:
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

colinoflynn, 2024-06-05:
This is in the r09 now, does that look OK? One obvious other change is G16 - that CE2, is that actually available, is it assigned to one of the SPIs?

marnovandermaas, 2024-06-06:
I've been following this site: https://pinout.xyz/pinout/spi
So I think it should be `RPH_G16_SPI1_CE2`

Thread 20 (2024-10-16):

PermitStoreLocalCap removed

marnovandermaas, 2024-10-16:
For future iterations of the board, we should remove the LED labelled `PStoreLCap` from the board. This has been removed from CHERIoT Ibex RTL.

More info here: https://github.com/lowRISC/sonata-system/issues/251

colinoflynn, 2025-01-08:
Can remove the LED etc as that is easy!

colinoflynn, 2025-01-08:
For design in A200 branch:
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

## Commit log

2023-12-07 Add first pass of Sonata design files
    [sb-sonata-analoginput.SchDoc, sb-sonata-debug.SchDoc, sb-sonata-ethmac.SchDoc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]
2023-12-07 Update PCB to r02, some silkscreen cleanup now done
    [cheriot-test.GBL, cheriot-test.GBO, cheriot-test.GBP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]
2023-12-07 Add FPGA pin maps
    [sonata-fpga-pins.csv]
2023-12-18 PCB updates, more bom doc done
2023-12-25 In-progress fixes for PCB & BOM
    [sb-sonata-debug.SchDoc, sonata-board.PrjPcb]
2024-01-03 Adds PCB fix for #3 - not sure where mirroring came from as OG symbol didn't have issue, must have been a problem later if part got swapped
2024-01-03 PCB fix for #1 - FTDI eeprom
2024-01-03 Updates to fix #4, RP/DIN routing
    [sb-sonata-fpgaio1.SchDoc, sonata-board.PrjPcb]
2024-01-03 Pinswap to fix #5, TCK routing
    [sb-sonata-fpgaio2.SchDoc]
2024-01-05 Change RS485 to show A(-), B(+). Had this backwards on exisitng silkscreen! Tracked in #8.
2024-01-05 Improve feedback layout for XADC reg. Bumb PCB rev to .03 to reflect ongoing changes.
    [sonata-board.PrjPcb]
2024-01-05 Change 485 net naming (related to #8)
    [sb-sonata-fpgaio1.SchDoc, sb-sonata-industriaal.SchDoc]
2024-01-11 Add PCB update for #9
    [sonata-board.PrjPcb]
2024-01-11 sw3/sw7 swap for #6
    [sb-sonata-fpgaio1.SchDoc]
2024-01-12 Various silkscreen improvements, adding more pin numbering, moving around logos a bit
2024-01-12 Add -03 PCB gerbers (possible still more updates)
    [cheriot-test.GBL, cheriot-test.GBO, cheriot-test.GBP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]
2024-01-12 Change LED level shifting transistor (BOM change only), for issue #10
    [sb-sonata-lcd.SchDoc, sb-sonata-led.SchDoc, sonata-board.PrjPcb]
2024-01-15 Fix PN of the QSPI flash to make them Winbond parts, change RP2040 one to a smaller part. Fix QWIIC label error.
    [sb-sonata-fpgaio1.SchDoc, sb-sonata-led.SchDoc, sb-sonata-usbrp.SchDoc]
2024-01-18 Adds PCB changes for #11, fix eth, also clean up placement on bottom to allow feet to fit
    [sb-sonata-ethmac.SchDoc, sb-sonata-industriaal.SchDoc]
2024-01-18 Add -r04 PCB
    [cheriot-test.GBL, cheriot-test.GBO, cheriot-test.GBP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]
2024-01-18 Project file wasnt' set to 04 rev, fixed
    [sonata-board.PrjPcb]
2024-01-22 PCB updates to 0.5RC, add pull-down option for #12, fix #13, fix some DRCs
    [sb-sonata-led.SchDoc, sonata-board.PrjPcb]
2024-01-22 Make LED driver pull-down by default until proven to be worse for #12
    [sb-sonata-led.SchDoc]
2024-01-22 Add -r05 files
    [cheriot-test.GBL, cheriot-test.GBO, cheriot-test.GBP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]
2024-01-22 Save the updated rev in project, update outjob
    [sonata-board.PrjPcb]
2024-01-26 Add pull-ups on R-Pi SCL/SDA, for #14. Also minor silkscreen cleanups.
    [sb-sonata-headers1.SchDoc, sonata-board.PrjPcb]
2024-02-02 Add minor bom updates, add R06 gerbers
    [cheriot-test.GBL, cheriot-test.GBO, cheriot-test.GBP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]
2024-02-09 Rev 07 - minor updates to RP2040 --> RGBLED connection
    [sb-sonata-led.SchDoc, sb-sonata-mech.SchDoc, sb-sonata-usbrp.SchDoc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]
2024-02-12 Add 03 & 05 FPGA pinouts
    [sonata-fpga-pins-r03.csv, sonata-fpga-pins-r05.csv]
2024-02-15 Minor silkscreen updates, fix arduino names
2024-02-15 Move P9 silkscreen
2024-02-16 Final tweaks, r08
    [cheriot-test.GBL, cheriot-test.GBO, cheriot-test.GBP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]
2024-02-25 Mark all schematic sheets as "approved", add minor doc notes
    [sb-sonata-analoginput.SchDoc, sb-sonata-debug.SchDoc, sb-sonata-ethmac.SchDoc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]
2024-02-25 Add link to URL for issues
    [sb-sonata-mech.SchDoc]
2024-02-25 Add r08 pdf schematic
2024-03-13 Update README.md with current status
2024-03-13 Change the render for a PCB
2024-05-23 Rev.09 in progress.
    [sb-sonata-ethmac.SchDoc, sb-sonata-fpgaio1.SchDoc, sb-sonata-usb.SchDoc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]
2024-05-23 Rev 09 - add mod notes on front page
    [sb-sonata-mech.SchDoc]
2024-06-05 Rev09: Silkscreen tweaks, change 10K to 12K to optimize BOM on pull-up
    [sb-sonata-fpgaio1.SchDoc]
2024-06-05 Add rev09 PCB, PNP file
    [NPCA-SONATA-ONE-REV09-PNP.csv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]
2024-06-05 Fix issue #18
    [sb-sonata-fpgaio1.SchDoc, sb-sonata-headers1.SchDoc]
2024-06-05 Rename RPH to add SPI0/SPI1 specific notation, per issue #19
    [sb-sonata-fpgaio1.SchDoc, sb-sonata-headers1.SchDoc]
2024-06-05 Update r09 schematic with changes suggested in #18 #19
    [sonata-board.PrjPcb]
2025-01-31 Move Sonata-One to new folder
    [NPCA-SONATA-ONE-REV09-PNP.csv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]
2025-01-31 Add A200 version
    [cheriot-test.GBL, cheriot-test.GBO, cheriot-test.GBP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]
2025-01-31 Merging KiCAD Source to main branch
    Merging KiCAD version of source to main branch. Physical diff from Altium source should be extremely minimal but it is worth noting that no boards have been manufactured from the KiCAD source as of t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
    [Analog_Conversion.kicad_sch, ETHMAC.kicad_sch, FPGA_ANA_1.8V.kicad_sch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]
2025-01-31 Move kicad to sonata-one directory
    [Analog_Conversion.kicad_sch, ETHMAC.kicad_sch, FPGA_ANA_1.8V.kicad_sch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]
2025-01-31 Improve readmes, move old files
    [cheriot-test.GBL, cheriot-test.GBO, cheriot-test.GBP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]
